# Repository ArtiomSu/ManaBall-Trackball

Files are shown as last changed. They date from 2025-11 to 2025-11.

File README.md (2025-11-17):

# Mana Ball Track Ball




A fully modular, open-source, 3D-printable trackball with customizable RGB lighting and swappable button modules. The Mana Ball features a translucent 50mm ball illuminated by 6 RGB LEDs, creating a glowing multicolor orb effect reminiscent of mana orbs in video games.

<p align="center">
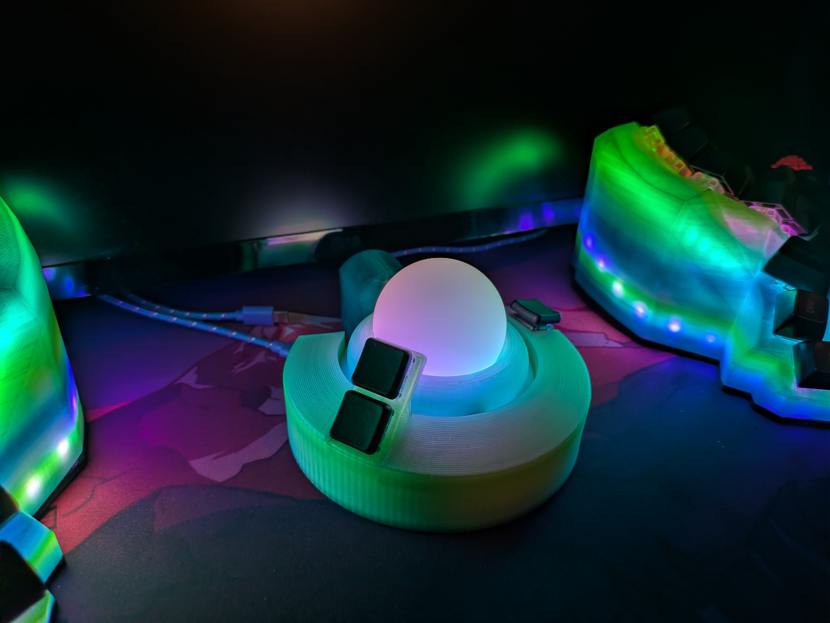
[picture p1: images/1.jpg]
Mana Ball Track Ball with button module
  
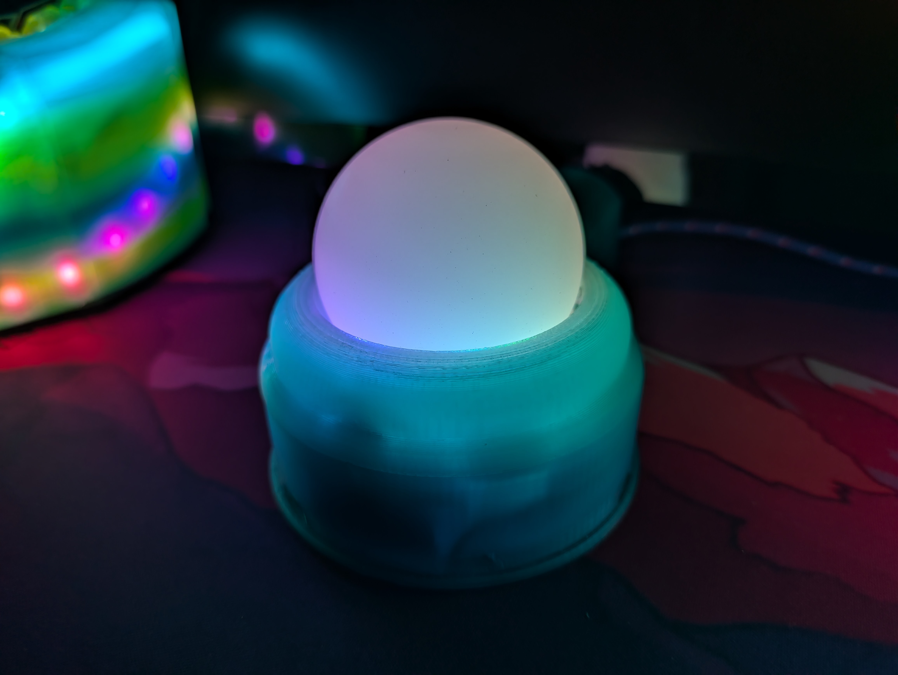
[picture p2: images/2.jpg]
Mana Ball Track Ball
  
</p>

See more photos in the [gallery](gallery.md).

Click the images below to watch introduction videos

| Mana Ball Trailer | Mana Ball Overview and Features |
|---|---|
| Mana Ball Trailer (https://www.youtube.com/watch?v=vn09xzBtV5k) | Mana Ball Overview and Features (https://www.youtube.com/watch?v=WPnU__LLYNc) |

## Table of Contents

- [Features](#features)
- [Why Mana Ball?](#why-mana-ball)
- [Getting Started](#getting-started)
  - [Materials and Tools](#materials-and-tools)
  - [3D Printing Files](#3d-printing-files)
- [Build Guide](#build-guide)
  - [Common Parts](#common-parts)
  - [Body Options](#body-options)
  - [Button Modules](#button-modules)
  - [Wrist Rests](#wrist-rests)
  - [Recommended Setup](#recommended-setup)
- [Assembly](#assembly)
  - [Wiring Diagrams](#wiring-diagrams)
  - [Assembly Videos](#assembly-videos)
- [Firmware](#firmware)
- [Configuration](#configuration)
- [Troubleshooting](#troubleshooting)
- [Contributing](#contributing)
- [License](#license)

## Features

- **Modular Design**: Hot-swappable button modules and body configurations
- **High Precision**: PMW3360 optical sensor for accurate tracking
- **Smooth Movement**: Rexroth Ball Transfer Units (BTUs) for premium feel
- **Customizable RGB**: 6 RGB LEDs with configurable lighting effects
- **Low Profile**: Ergonomic design with low-profile keyboard switches
- **Drag Scrolling**: Configurable scroll feature
- **Universal Compatibility**: Works with all operating systems via USB-C
- **Open Source**: Fully 3D printable with no custom PCBs required
- **QMK Powered**: RP2040 microcontroller running QMK firmware
- **Adjustable Settings**: Pointer speed, scroll speed, scroll direction and LED effects
- **Standard Components**: Uses any 50mm ball

## Why Mana Ball?

After years of testing various trackballs (documented in my [trackball comparison repository](https://github.com/ArtiomSu/artiomsu-trackball-comparisons-and-mods)), I found that none perfectly suited my needs. While the Ploopy Adept came close after modifications, its button layout still wasn't ideal. The Mana Ball is my solution—a trackball designed specifically for my workflow, with modularity built in so others can adapt it to theirs.

**Best used with**: A QMK-enabled keyboard or macro pad configured with [QMK RAW HID Router Software](https://github.com/ArtiomSu/QMK-Raw-HID-Router) for full customization capabilities. While the trackball can operate standalone with button modules, the HID Router unlocks features like real-time configuration.

## Getting Started

### Materials and Tools

See [materials.md](materials.md) for the complete parts list and required tools.

**What you'll need depends on your build**:
- Skip LEDs if you don't want lighting effects
- Skip hot-melt inserts if not using the optional sensor holder
- Skip keycaps/switches if building a button-less version

**Cost considerations**: The most expensive components are the Rexroth BTUs, which provide the smoothest tracking experience but are surprisingly expensive. All other parts are reasonably priced.

### 3D Printing Files

All STL files are in the [`finished stl/`](<finished stl/>) folder.

**Bambu Studio users**: A pre-configured `.3mf` project file is included with optimized print settings and bed arrangement.

This is also uploaded to [Makers World](https://makerworld.com/en/models/2009889-mana-ball-track-ball) so you can download it directly to your Bambu Lab printer if you have one.

## Build Guide

### Common Parts

These parts are required for all builds:

| Part | File | Notes |
| ---- | ---- | ----- |
| **Head** | [head.stl](<finished stl/head.stl>) | Main component holding the ball and sensor |
| **Shim** | [shim.stl](<finished stl/shim.stl>) | Secures the microcontroller inside the body |
| **Head Sensor Holder** | [head_sensor_holder.stl](<finished stl/head_sensor_holder.stl>) | Optional: Provides extra sensor security (requires hot-melt inserts in head) |

### Body Options

#### Button-Less Bodies

For use with an external keyboard for clicking:

| Part | File | Description |
| ---- | ---- | --- |
| **Body Medium** | [body_medium.stl](<finished stl/body_medium.stl>) | One-piece design with integrated controller placement. Clean aesthetics but taller profile |
| **Body Small** | [body_small.stl](<finished stl/body_small.stl>) | Compact design requiring [body_small_cap.stl](<finished stl/body_small_cap.stl>) |
| **Body Small Cap** | [body_small_cap.stl](<finished stl/body_small_cap.stl>) | Cap for small body, conceals wiring |
| **Body Small External** | [body_small_external.stl](<finished stl/body_small_external.stl>) | Compact with exposed controller. Lower profile but visible wires (test design) |

#### Bodies with Button Support

| Part | File | Description |
| ---- | ---- | --- |
| **Body Small for Buttons** | [body_small_for_buttons.stl](<finished stl/body_small_for_buttons.stl>) | Standard button-compatible body. Uses [body_small_cap.stl](<finished stl/body_small_cap.stl>) |
| **Body Small for Buttons (Wire Friendly)** | [body_small_for_buttons_bigger_more_wire_cutouts.stl](<finished stl/body_small_for_buttons_bigger_more_wire_cutouts.stl>) | Enhanced wire routing with larger cutouts. Uses [body_small_cap.stl](<finished stl/body_small_cap.stl>) |

### Button Modules

Located in [`finished stl/buttons/`](<finished stl/buttons/>).

**Note**: Button modules are functional but still WIP. Current designs provide working button positions but aesthetics are being refined.

**Compatibility**: Any button-compatible body works with any button module.

Some button modules use a cover that is secured with magnets. For example the [triple button v3.1](<finished stl/buttons/triple button v3.1.stl>) would go together with [triple button v3.1 cover](<finished stl/buttons/triple button v3.1 cover.stl>).

### Wrist rests

Located in [`finished stl/wrist rest/`](<finished stl/wrist rest/>).

**Note**: This is recommended as the ball is quite high.

**Printing tip**: Print with TPU with 1 wall for top/bottom and sides. Use 5% infill for maximum comfort. This way it keeps its shape but is just a little bit soft.

### Recommended Setup

**My current configuration**:
- Body: [body_small_for_buttons_bigger_more_wire_cutouts.stl](<finished stl/body_small_for_buttons_bigger_more_wire_cutouts.stl>)
- Buttons: [triple button v3.1](<finished stl/buttons/triple button v3.1.stl>) with [triple button v3.1 cover](<finished stl/buttons/triple button v3.1 cover.stl>).
- Wrist Rest: [wrist rest.stl](<finished stl/wrist rest/wrist rest.stl>)
- Layout: Left click, right click, and drag scroll—perfect for my workflow

## Assembly

### Wiring Diagrams

#### Without Switches

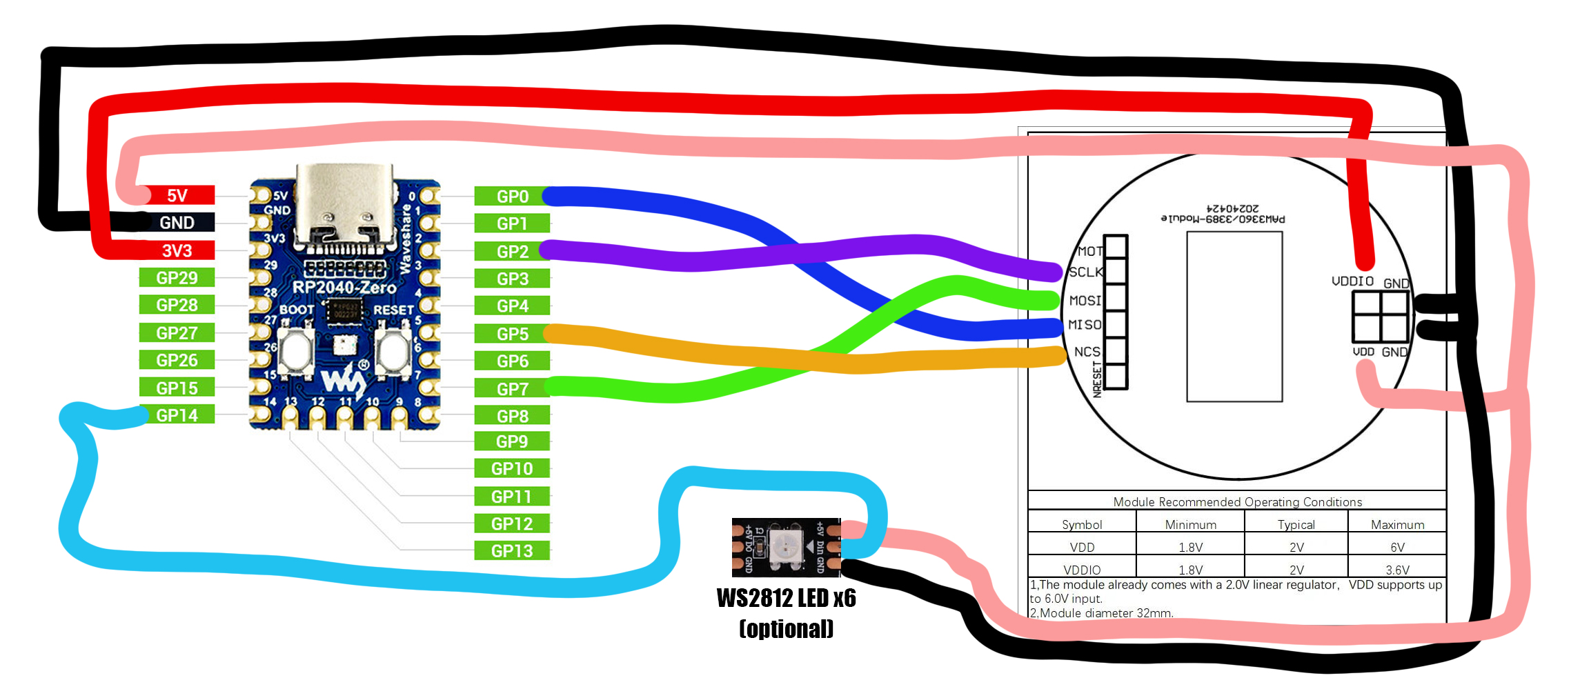
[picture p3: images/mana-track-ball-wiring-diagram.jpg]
Wiring Diagram without Switches


#### With Switches

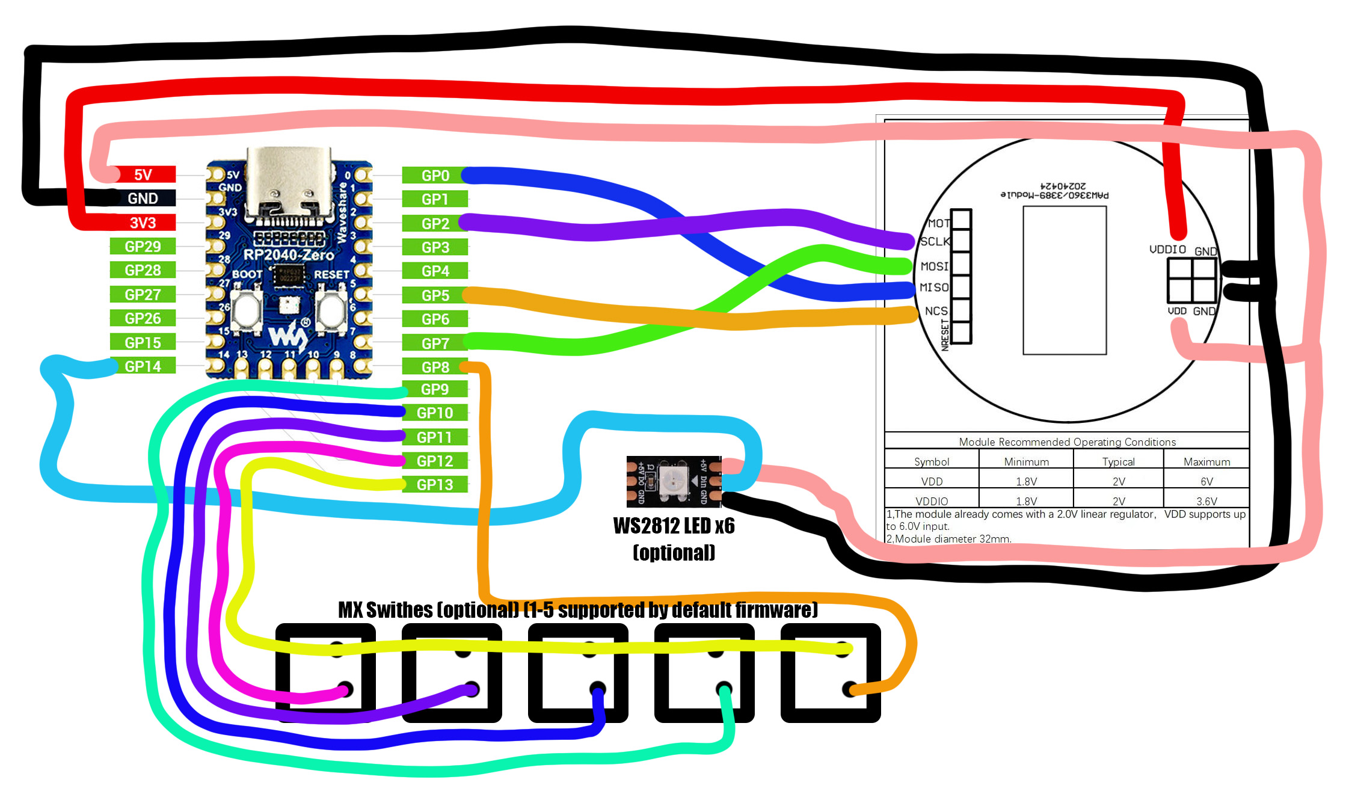
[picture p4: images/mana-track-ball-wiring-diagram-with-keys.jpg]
Wiring Diagram with Switches


**Important notes**:
- **No diodes required**: Single-row, five-column matrix supports n-key rollover without diodes
- **Expandable**: 9 additional free GPIO pins available for up to 14 total switches (requires quick firmware modification)
- **Flexible switch count**: Using fewer than 5 switches? Just populate the pins you need (starting with GP12). Unpopulated switches are simply ignored by firmware

### Assembly Videos

Follow these step-by-step video guides:

1. **[Head Assembly](https://youtu.be/o33xUQOpQcM)** - Start here, as this is the most complex and universal component
2. **[Body Assembly](https://youtu.be/YjRsaHhR8Q8)** - Attach your chosen body
3. **[Better Button Module Assembly](https://www.youtube.com/watch?v=52Slw13G3vc)** - Add buttons (if applicable)

## Firmware

### Flashing QMK Firmware

**Prerequisite**: Set up QMK on your system following the [official QMK setup guide](https://docs.qmk.fm/#/newbs_getting_started).

```bash
# Clone the firmware repository
git clone https://github.com/ArtiomSu/qmk_firmware.git
cd qmk_firmware

# Switch to the Mana Ball branch
git checkout artiomsu_manaball

# Initialize submodules
qmk git-submodule

# Clean and flash
make clean
qmk flash -kb artiomsu_manaball -km default
```

**Tip**: Flash firmware before wiring to verify the microcontroller works correctly.

If you don't want to customise the firmware, you can download pre-compiled `.uf2` files from the [Releases](https://github.com/ArtiomSu/ManaBall-Trackball/releases).

Drag and drop the `.uf2` file onto the RP2040 mounted as a USB drive. To mount the RP2040 as a USB drive, hold the BOOTSEL button while plugging it into your computer.

## Configuration

### Customizing Settings

Adjust pointer speed, scroll behavior, LED effects, and more using the [QMK RAW HID Router Software](https://github.com/ArtiomSu/QMK-Raw-HID-Router).

**Platform support**: Windows, Linux, and macOS

**Setup process**:
1. The Mana Ball is pre-configured for the HID Router
2. Configure your QMK keyboard/macro pad following the [video tutorial](https://github.com/ArtiomSu/QMK-Raw-HID-Router) at the bottom of the README
3. Control trackball settings via keyboard shortcuts

**Reference implementation**: See my [keyboard firmware](https://github.com/ArtiomSu/qmk_firmware/tree/artiom_dactyl/keyboards/artiomsu_dactyl/keymaps/linux_and_mac) for integration examples.

**Future plans**: Standalone configuration app (desktop or web-based) may be developed, but keyboard integration offers superior workflow integration with layers, macros, and synchronized settings.

## Troubleshooting

**Common Issues**:

- **Ball doesn't track smoothly**: Check BTU alignment and cleanliness
- **LEDs not lighting**: Verify LED wiring polarity and connections
- **Sensor not working**: Ensure sensor is properly seated and lens is clean
- **Buttons not responding**: Check switch wiring and verify GPIO pin connections
- **Firmware won't flash**: Ensure RP2040 is in bootloader mode (hold BOOTSEL while connecting)

**Need help?** Open an issue on GitHub with:
- Photos of your build
- Description of the problem
- What you've already tried

## Contributing

Contributions are welcome! Whether you've designed a new button module, improved a body design, or found a bug:

1. Fork the repository
2. Create a feature branch
3. Submit a pull request with clear descriptions

**Share your builds**: I'd love to see your custom modules and modifications!

## License

This project is licensed under the Creative Commons Attribution-NonCommercial-ShareAlike 4.0 International License (CC BY-NC-SA 4.0).

**This means**:
- ✅ You can use, modify, and share this design
- ✅ You must share any modifications under the same license
- ✅ You must give appropriate credit
- ❌ You cannot use this commercially without permission

See [LICENSE](LICENSE) for the full license text.

---

**Questions?** Open an issue on GitHub or check the [QMK RAW HID Router](https://github.com/ArtiomSu/QMK-Raw-HID-Router) documentation for configuration help.

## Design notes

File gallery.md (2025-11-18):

# Mana Ball Track Ball Gallery

A visual showcase of the Mana Ball's design.

## Gallery

<table>
  <tr>
    <td width="50%">
      Mana Ball - View 1
    </td>
    <td width="50%">
      Mana Ball - View 2
    </td>
  </tr>
  <tr>
    <td width="50%">
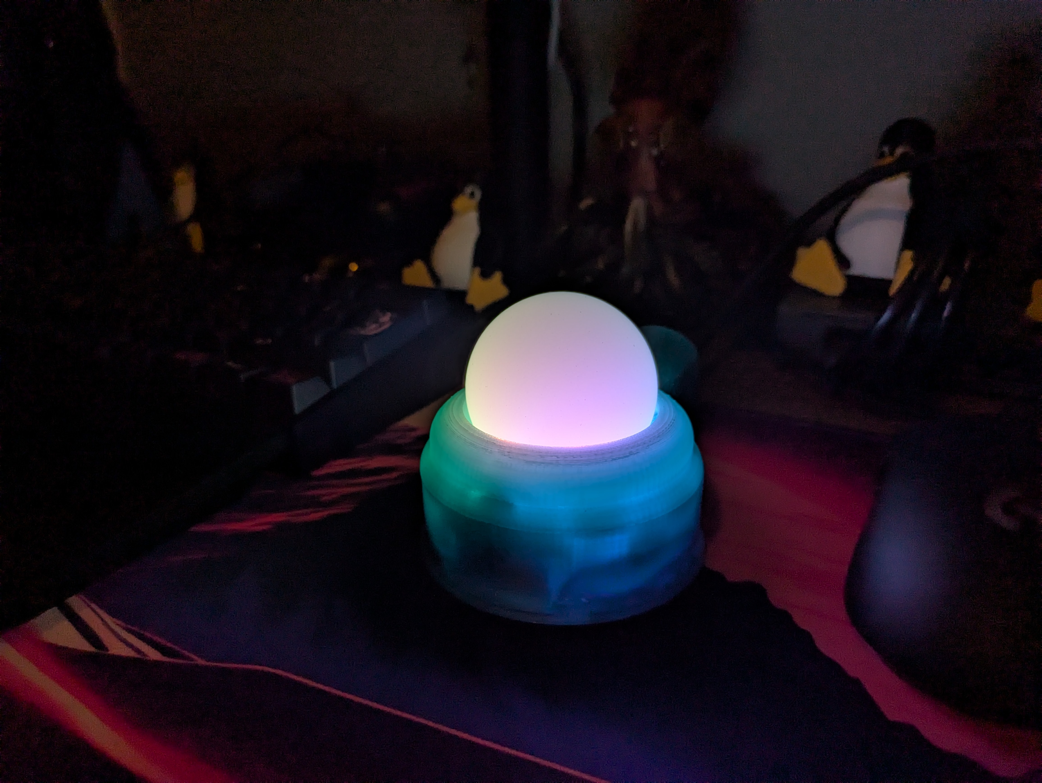
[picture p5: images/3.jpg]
Mana Ball - View 3
      
    </td>
    <td width="50%">
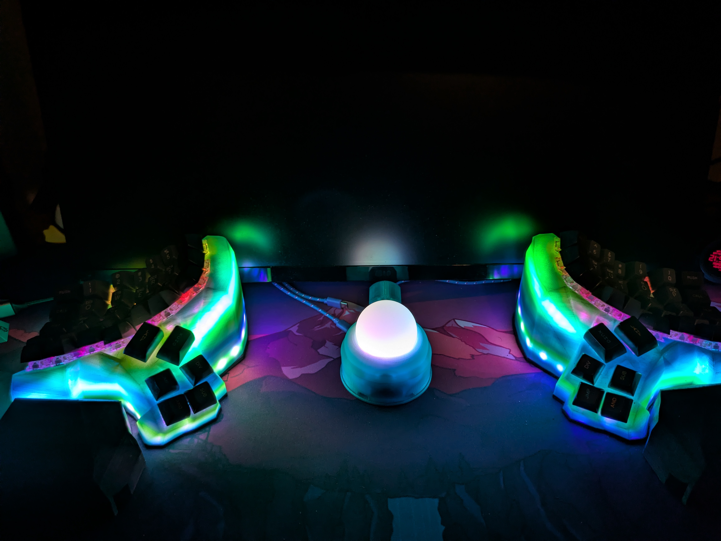
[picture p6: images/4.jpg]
Mana Ball - View 4
      
    </td>
  </tr>
  <tr>
    <td width="50%">
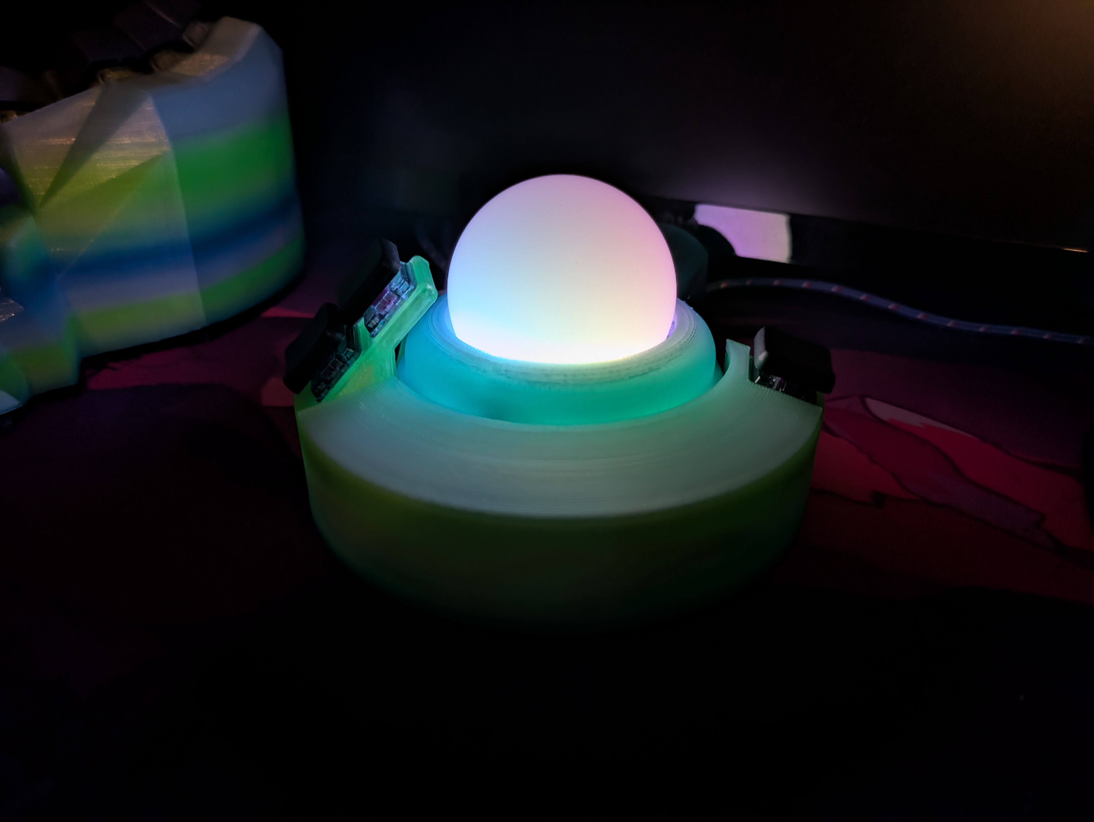
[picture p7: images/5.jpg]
Mana Ball - View 5
      
    </td>
    <td width="50%">
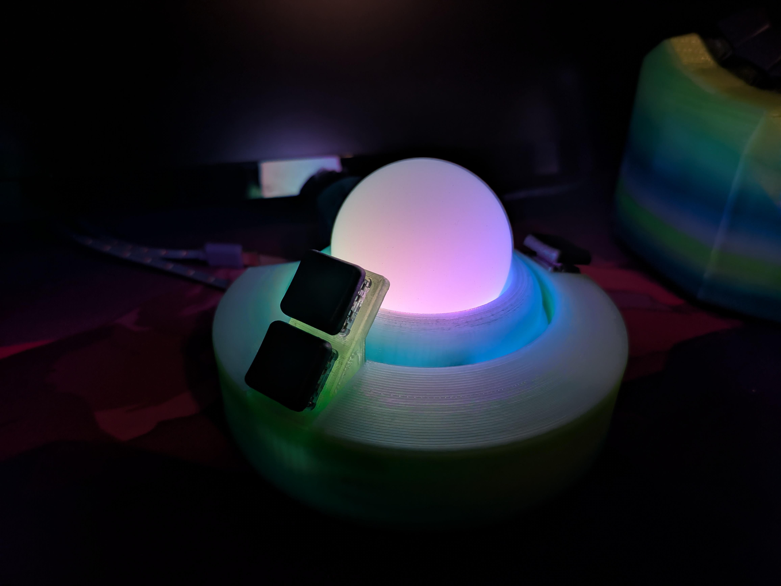
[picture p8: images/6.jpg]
Mana Ball - View 6
      
    </td>
  </tr>
  <tr>
    <td width="50%">
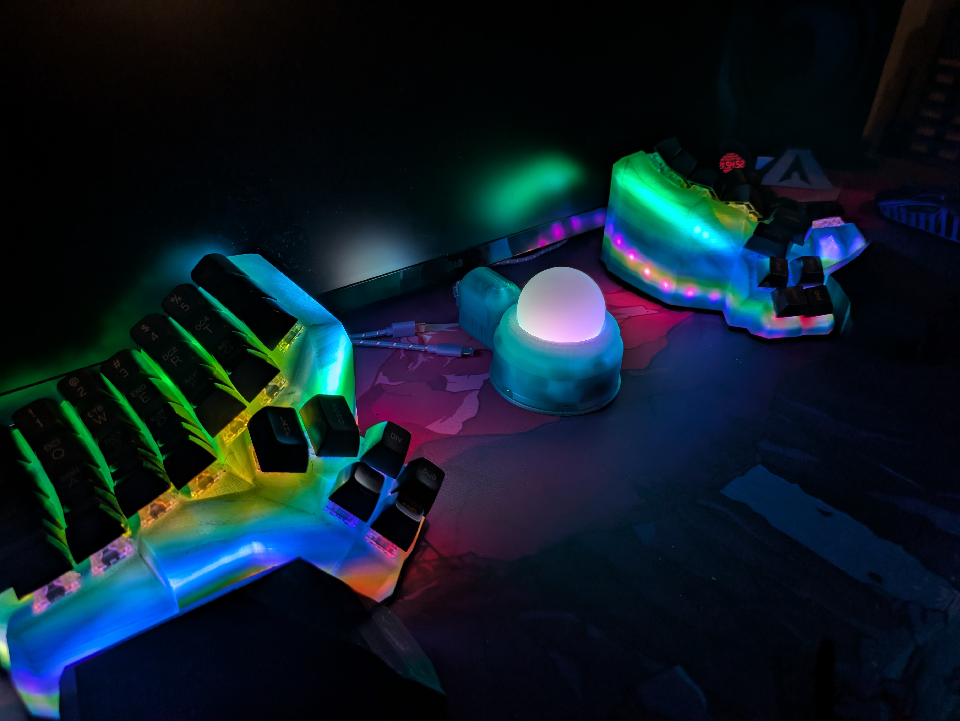
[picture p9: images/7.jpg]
Mana Ball - View 7
      
    </td>
    <td width="50%">
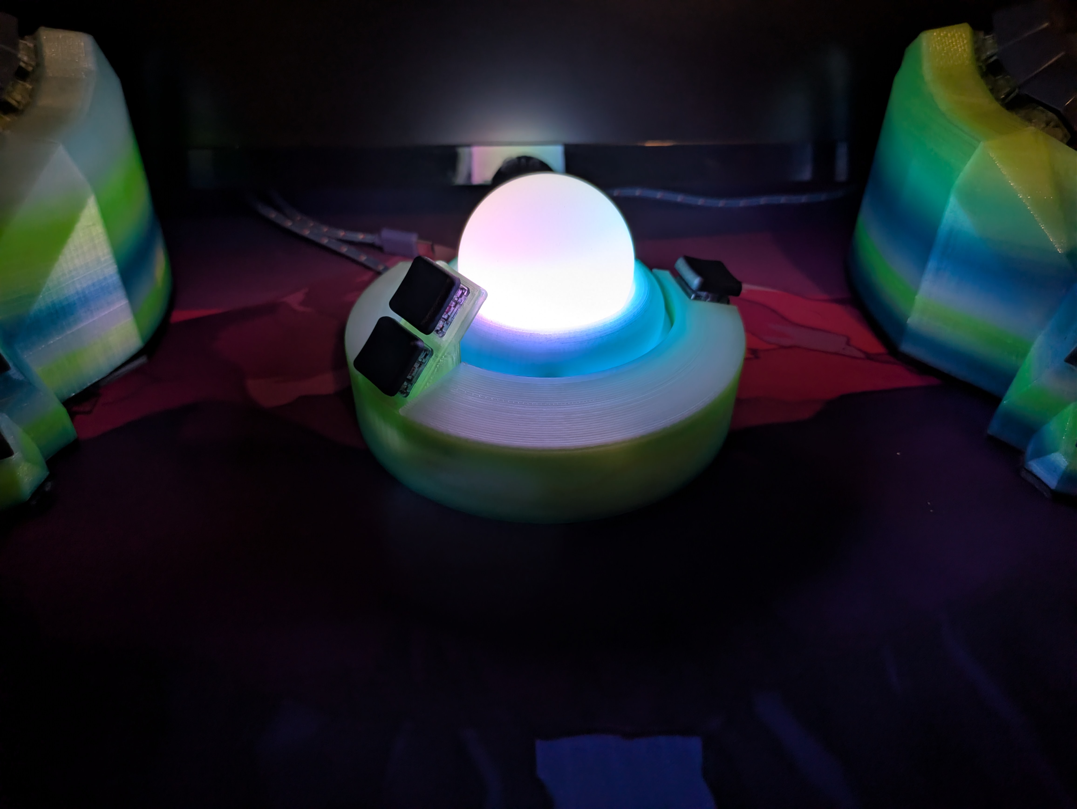
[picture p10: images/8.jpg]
Mana Ball - View 8
      
    </td>
  </tr>
  <tr>
    <td width="50%">
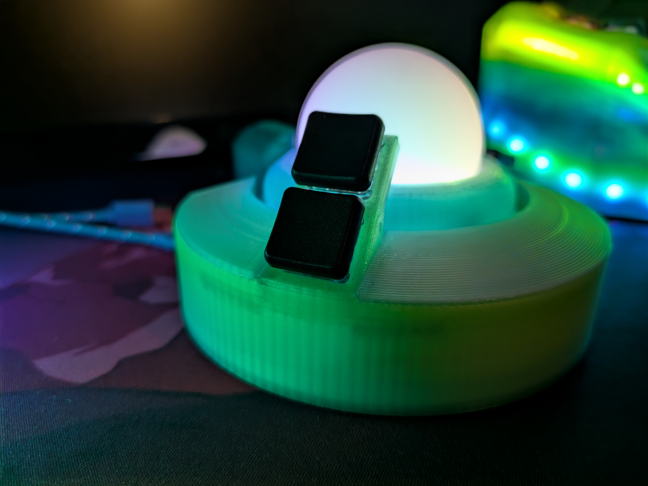
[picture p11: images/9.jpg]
Mana Ball - View 9
      
    </td>
    <td width="50%">
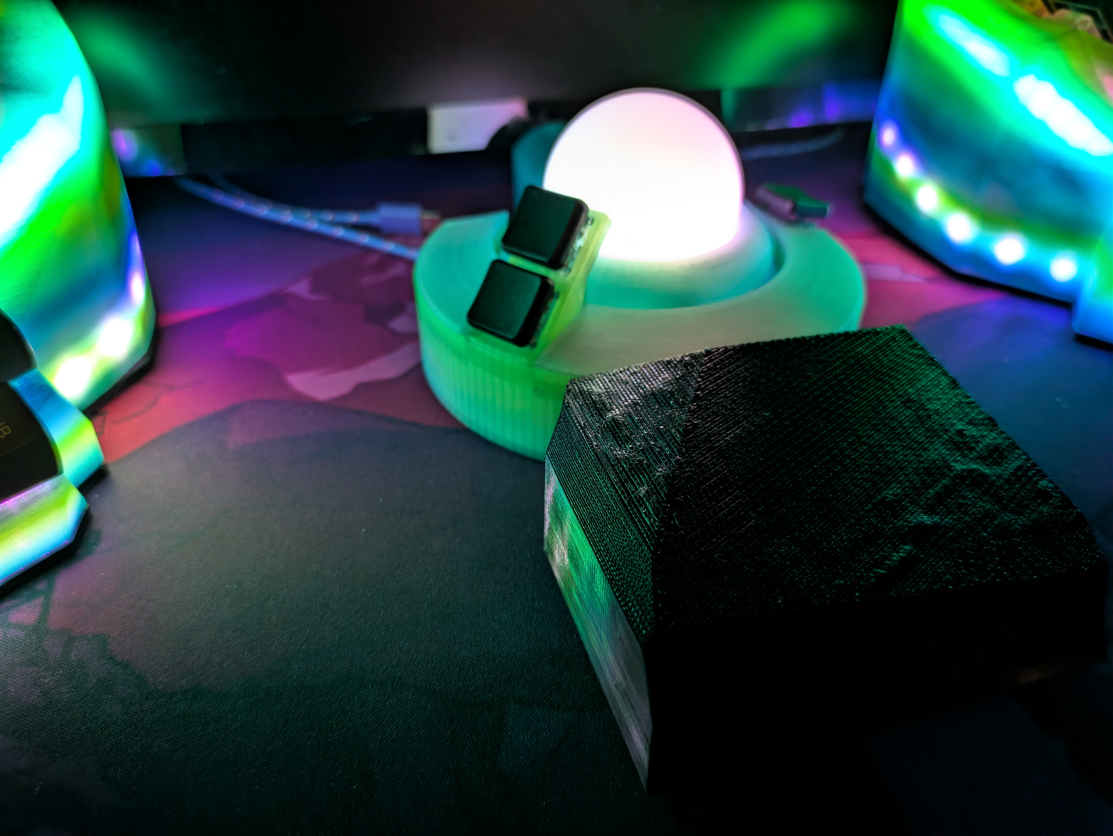
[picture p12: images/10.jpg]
Mana Ball - View 10
      
    </td>
  </tr>
  <tr>
    <td width="50%">
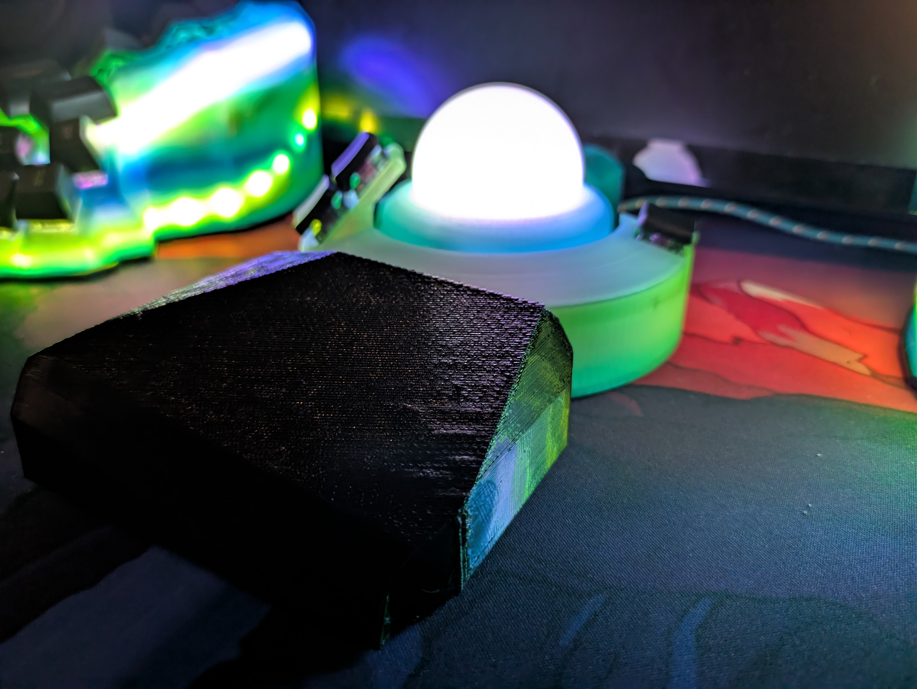
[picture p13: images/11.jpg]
Mana Ball - View 11
      
    </td>
    <td width="50%">
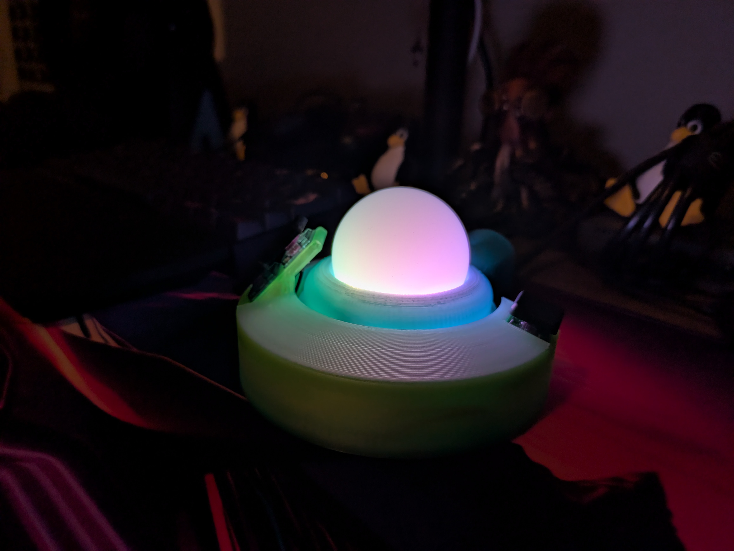
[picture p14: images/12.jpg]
Mana Ball - View 12
      
    </td>
  </tr>
  <tr>
    <td width="50%">
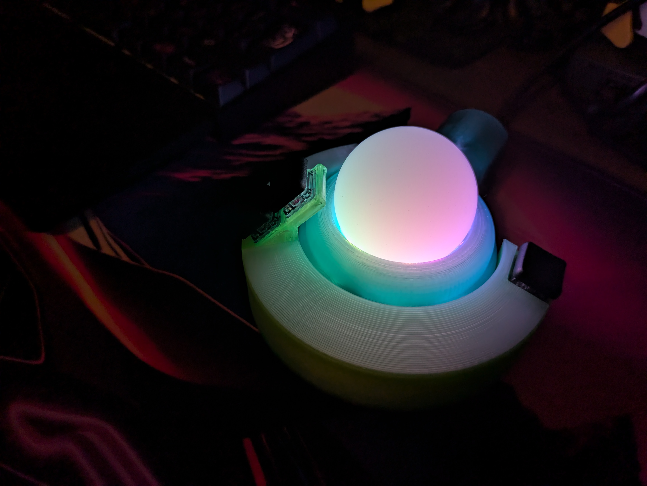
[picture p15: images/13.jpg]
Mana Ball - View 13
      
    </td>
    <td width="50%">
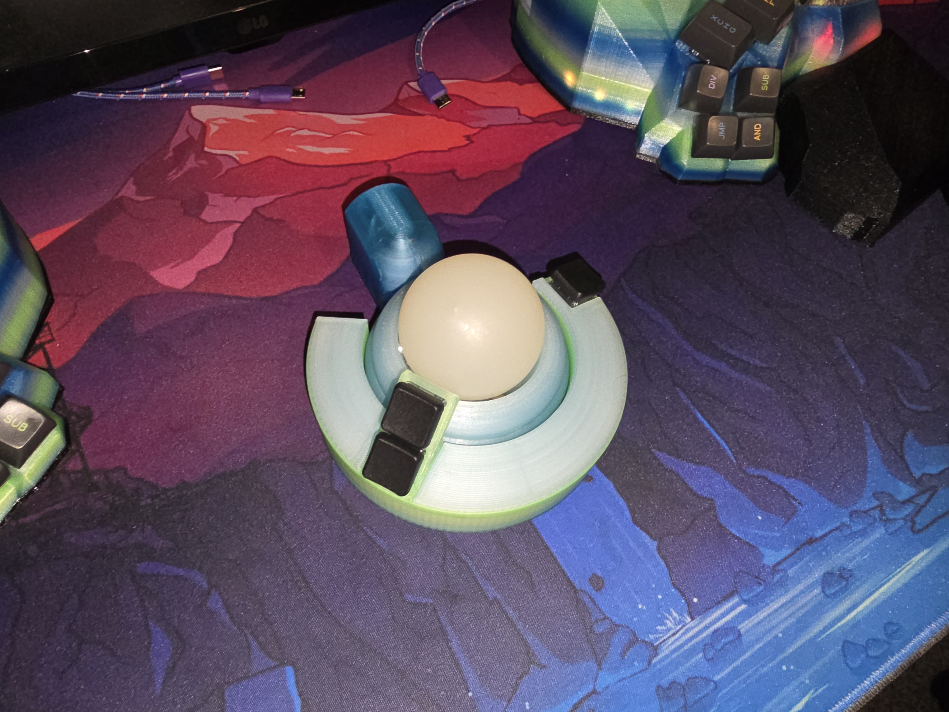
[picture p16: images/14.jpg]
Mana Ball - View 14
      
    </td>
  </tr>
  <tr>
    <td width="50%">
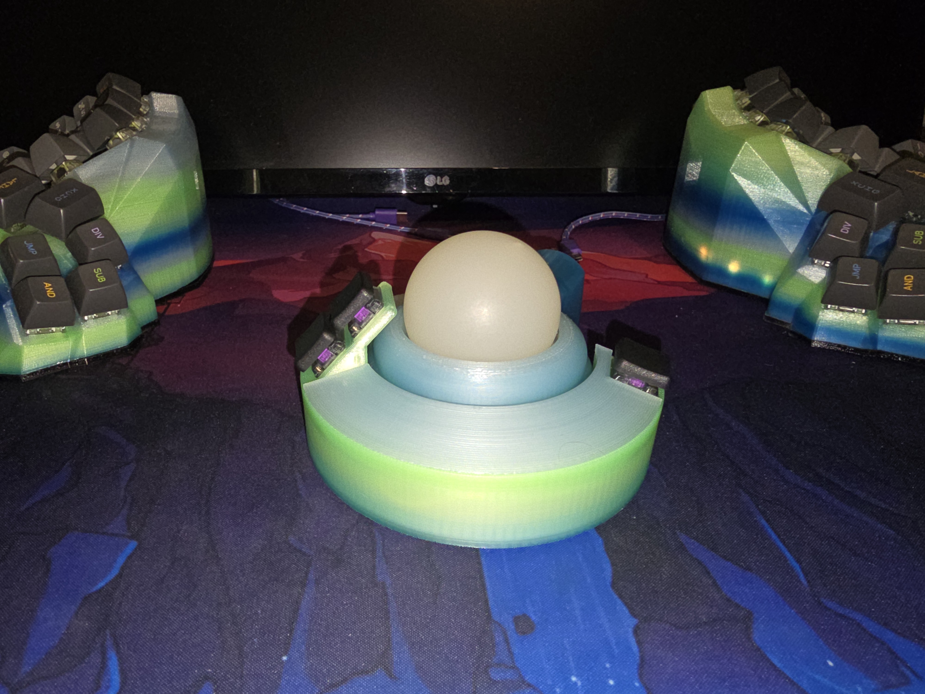
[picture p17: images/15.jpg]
Mana Ball - View 15
      
    </td>
    <td width="50%">
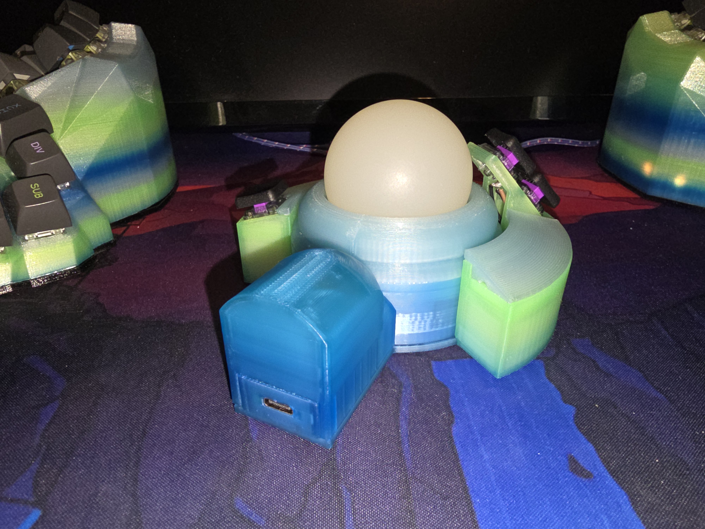
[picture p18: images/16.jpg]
Mana Ball - View 16
      
    </td>
  </tr>
  <tr>
    <td colspan="2" align="center">
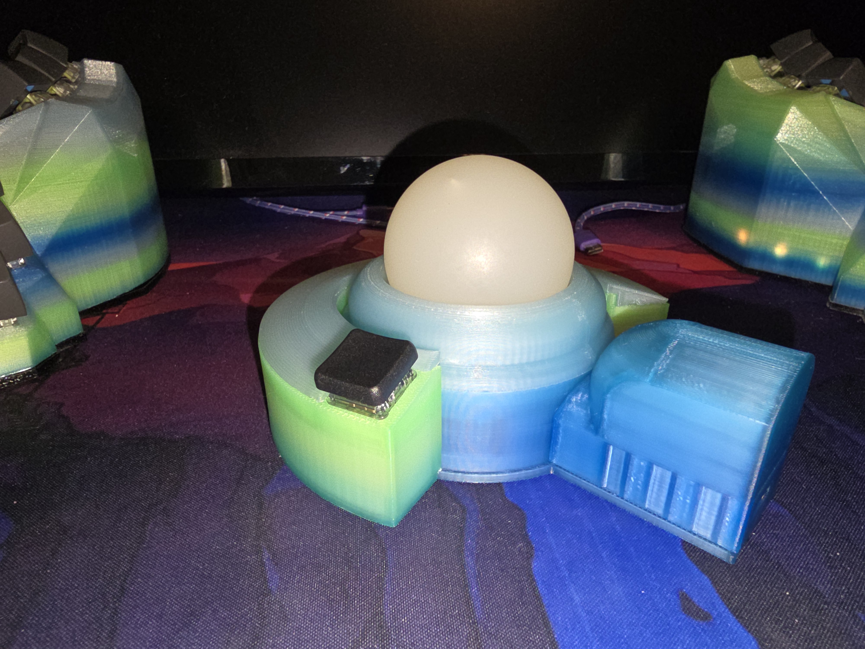
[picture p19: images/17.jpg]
Mana Ball - View 17
      
    </td>
  </tr>
</table>

---

[← Back to README](README.md)

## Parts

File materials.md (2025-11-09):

# Parts list for Mana Track Ball

| quantity | optional | part | link | price |
| --- | --- | ---- | ---- | ----- |
| 1 | No  | PMW3360 module | [aliexpress](https://www.aliexpress.com/item/1005007729769668.html) | ~€22 |
| 3 | No  | Rexroth BTU | [spareparts](https://www.sp-spareparts.com/en/p/r053010810-bosch-rexroth) | ~€50 |
| 1 | No  | rp2040 zero usb c | [aliexpress](https://www.aliexpress.com/item/1005007650325892.html) | €3 |
| 1 | No  | 50mm POM ball | [aliexpress](https://www.aliexpress.com/item/1005005059570859.html) | €7 |
| 2 | Yes | hot melt insert m2 (OD 3.2mm) 50 pack | [aliexpress](https://www.aliexpress.com/item/1005003582355741.html) | €2.50 |
| 2 | Yes | m2 10mm bolt 50 pack | [aliexpress](https://www.aliexpress.com/item/32810852732.html) | €2.00 |
| 1 | Yes | Rubber feet 6mm (pack of 50, we will only use 6) | [aliexpress](https://www.aliexpress.com/item/32963141746.html) | €3 |
| 1 | Yes | LED strip 144 leds/m (we will only use 6 leds from whole strip) | [aliexpress](https://www.aliexpress.com/item/1005007982624217.html) | €10 |
| 6 | No | 10mm x 1mm round magnets 50 pack | [aliexpress](https://www.aliexpress.com/w/wholesale-magnets-neodymium-10x1mm.html) | €2.50 |
| 1+ | Yes | Low profile keycaps (6 pack) | [aliexpress](https://www.aliexpress.com/item/1005005902080016.html) | €3.30 |
| 1+ | Yes | Low profile switch (10 pack) | [aliexpress](https://www.aliexpress.com/item/1005005066585322.html) | €8.41 |

The hot melt insert stuff above is optional because the friction fit is more than good enough for the sensor. If the sensor falls out for you, then you can secure it with the inserts and m2 screws.

The leds are also optional if you don't want the led lights for some reason, the firmware will still work without any leds attached since it doesn't really care if you have the pin connected or not, it will still send out the signal into thin air.

# Tools needed to Make it

| tool | link | price |
| ---- | ---- | ----- |
| soldering iron with adjustable temperature | got some random one on amazon | €20 |
| long nose pliers | got some random one in local shop | €3 |
| 3d printer (any will do these days. I use the Bambu labs a1)  | Bambu Labs EU | €500 |
| any filament you want (need only around 100g depending on your infill %) | amazon | €20 |
| Wire cutters (these should already be part of your 3d printer tools) | aliexpress | €3 |
| helping hands (to hold the wires while you are soldering) | local shop | €20 |
| wires for connecting everything (10 pin ribbon cable) can also use the regular arduino ones so you can easily connect and disconnect | [amazon](https://www.amazon.co.uk/dp/B09R42ZGQD) | €7 |
| hot melt insert kit | [aliexpress](https://www.aliexpress.com/item/1005006208845574.html) | €4 |

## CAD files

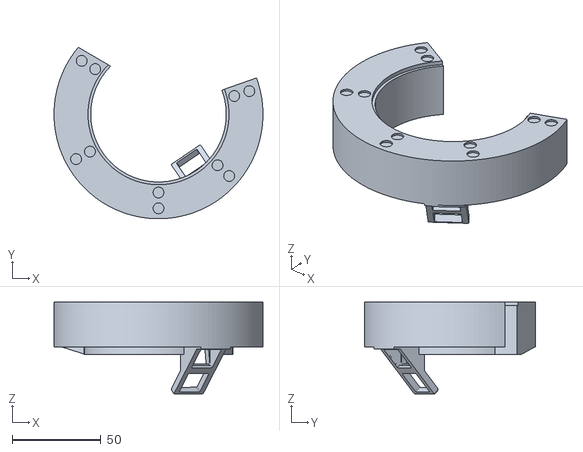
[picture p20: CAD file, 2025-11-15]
finished stl/buttons/triple button v3.1.stl
118.0 x 96.8 x 51.8

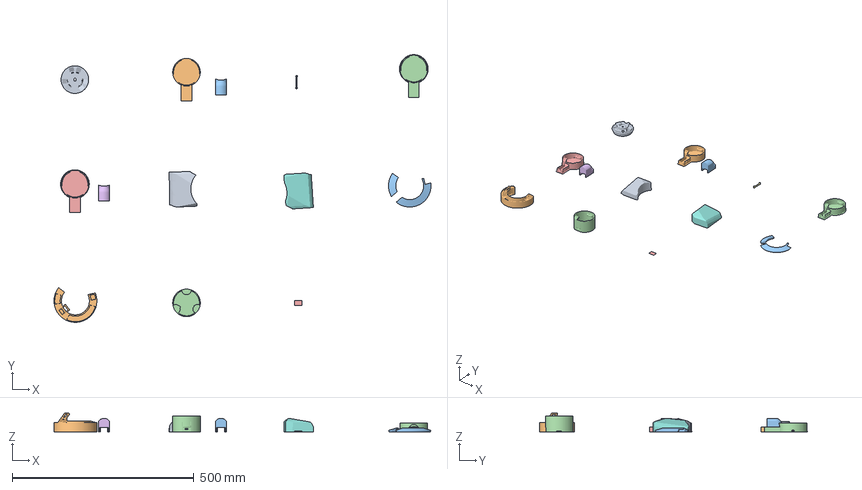
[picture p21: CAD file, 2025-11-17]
finished stl/head.3mf
1037.3 x 736.6 x 51.8 mm
head.stl
body_small.stl
body_small_cap.stl x 2
body_small_for_buttons.stl
body_small_for_buttons_bigger_more_wire_cutouts.stl
head_sensor_holder.stl
wrist rest.stl
wrist rest deeper.stl
triple button v3.1.stl
triple button v3.1 cover.stl
body_medium.stl
shim.stl

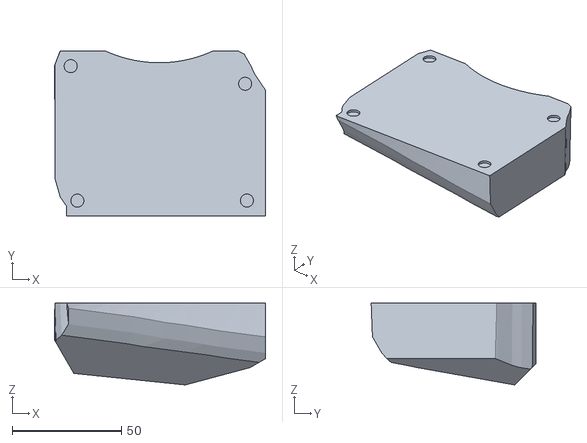
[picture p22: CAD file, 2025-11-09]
finished stl/wrist rest/wrist rest.stl
96.6 x 75.4 x 37.5

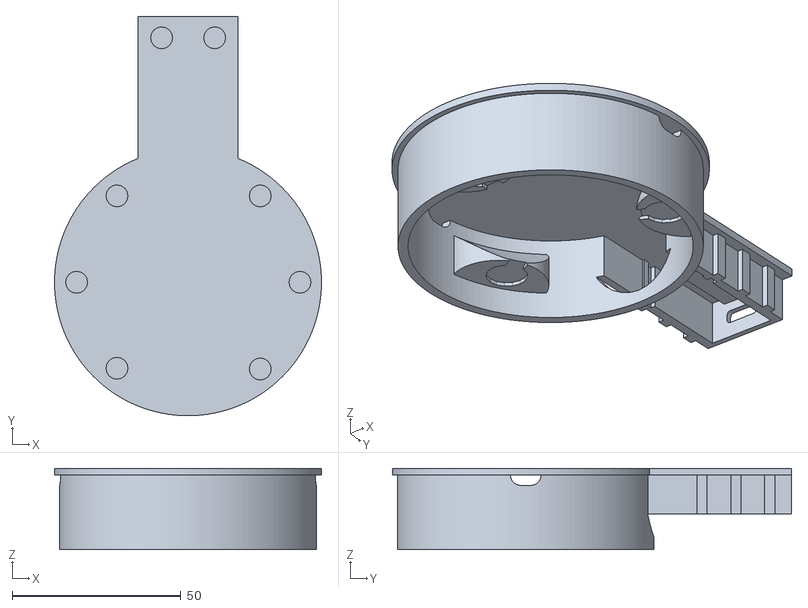
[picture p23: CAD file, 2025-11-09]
finished stl/body_small_for_buttons.stl
79.0 x 118.2 x 24.0

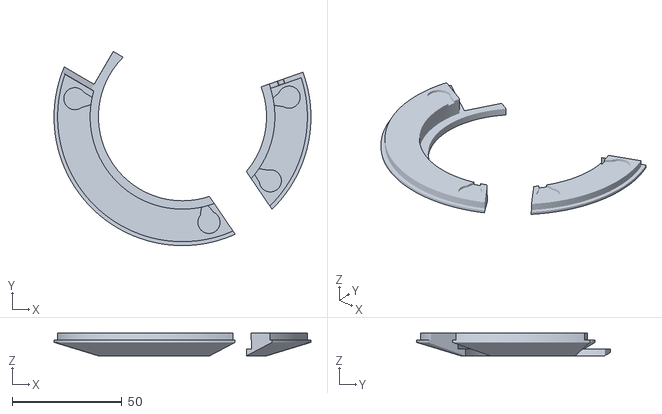
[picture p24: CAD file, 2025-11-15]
finished stl/buttons/triple button v3.1 cover.stl
117.0 x 88.4 x 10.2

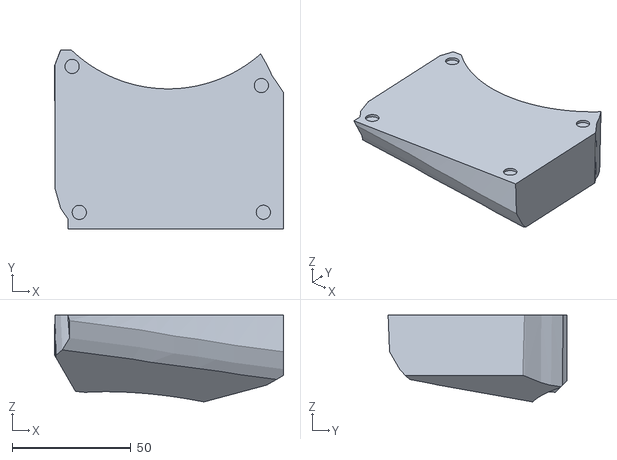
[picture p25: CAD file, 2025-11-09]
finished stl/wrist rest/wrist rest deeper.stl
96.6 x 75.4 x 36.6

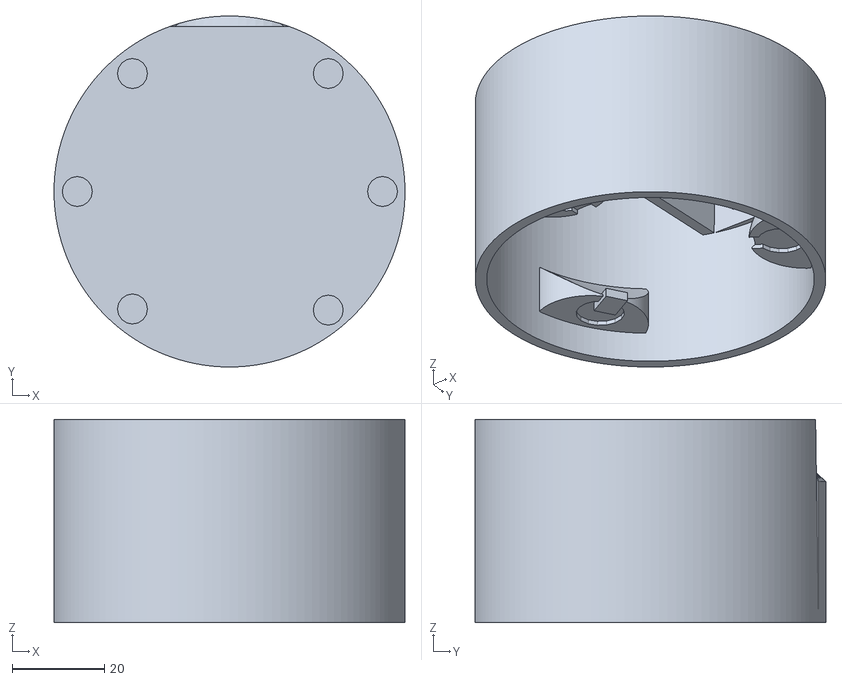
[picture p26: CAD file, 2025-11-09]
finished stl/body_medium.stl
76.0 x 76.0 x 44.0

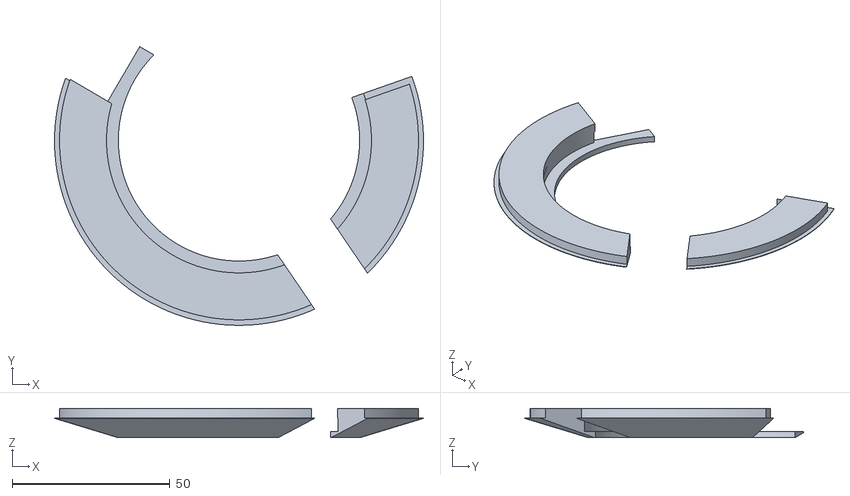
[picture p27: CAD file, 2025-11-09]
finished stl/buttons/triple button v2 cover v2.1.stl
117.0 x 88.4 x 9.24

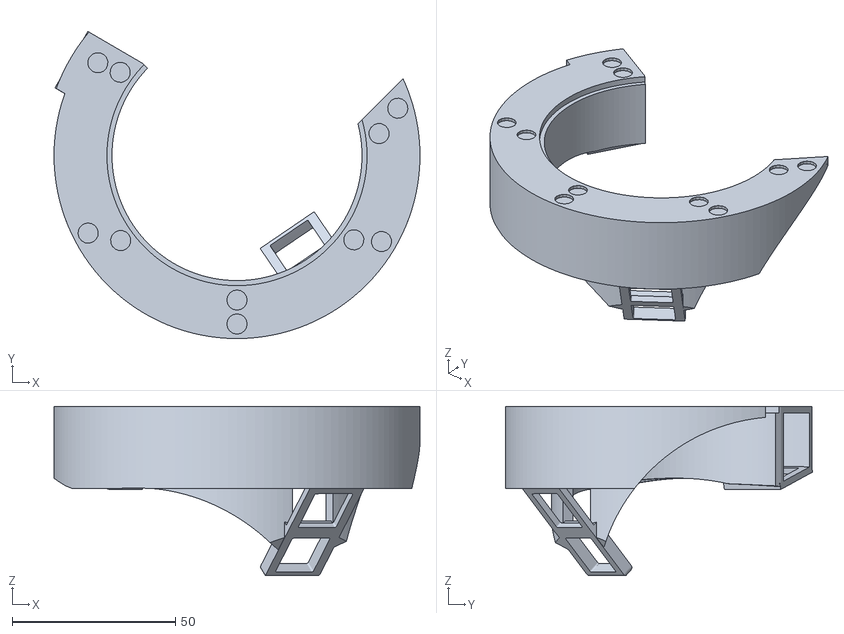
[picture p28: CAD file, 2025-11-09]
finished stl/buttons/simple triple button test v2 higher.stl
112.0 x 94.0 x 51.8

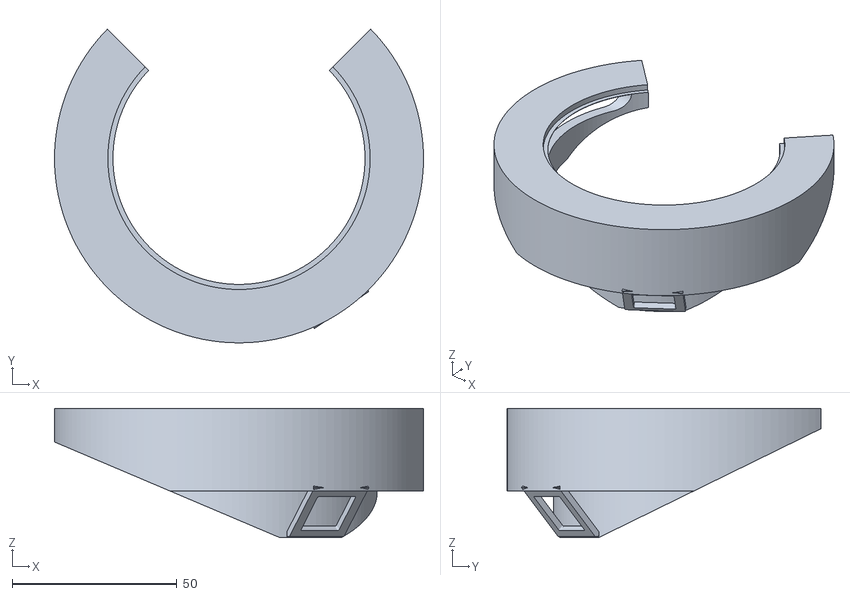
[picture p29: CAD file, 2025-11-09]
finished stl/buttons/simple single button test flipped v2.stl
112.0 x 95.2 x 39.2

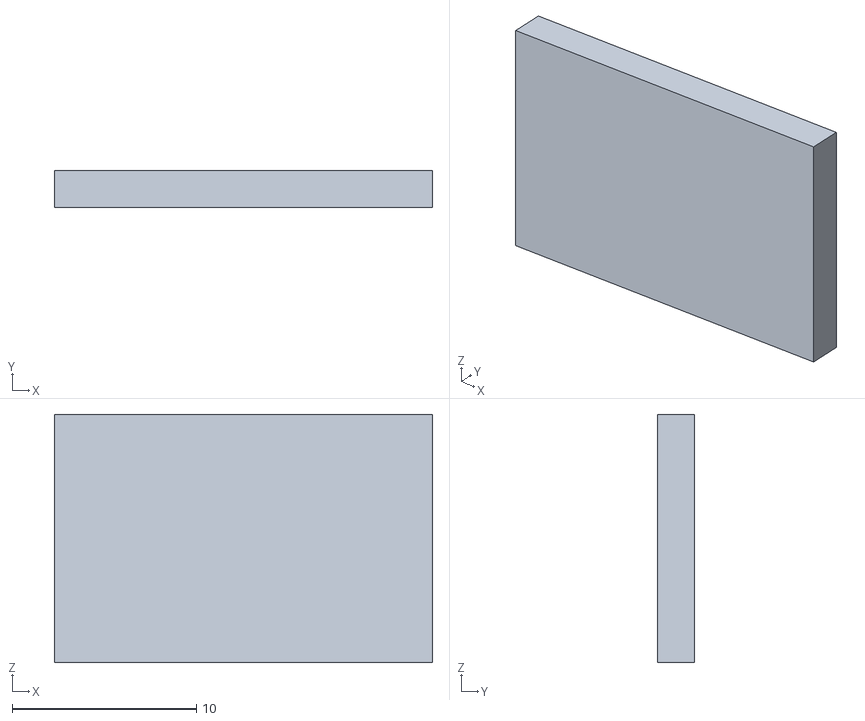
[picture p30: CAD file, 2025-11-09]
finished stl/shim.stl
20.5 x 2.00 x 13.5

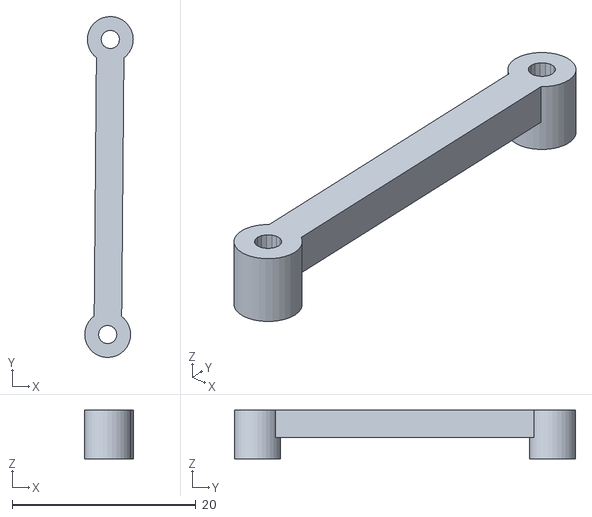
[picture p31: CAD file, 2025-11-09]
finished stl/head_sensor_holder.stl
5.29 x 37.1 x 5.30

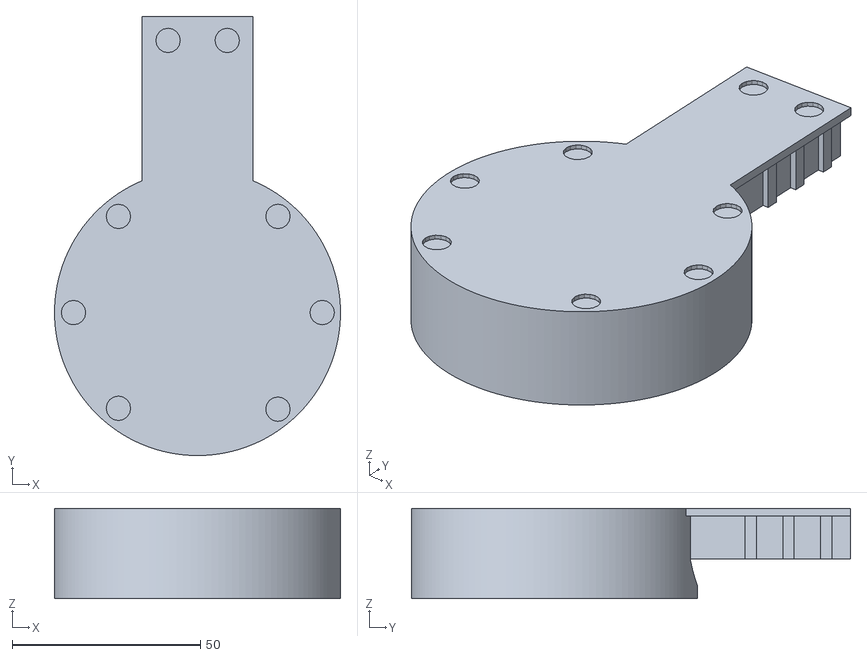
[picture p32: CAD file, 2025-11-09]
finished stl/body_small.stl
76.0 x 116.7 x 24.0

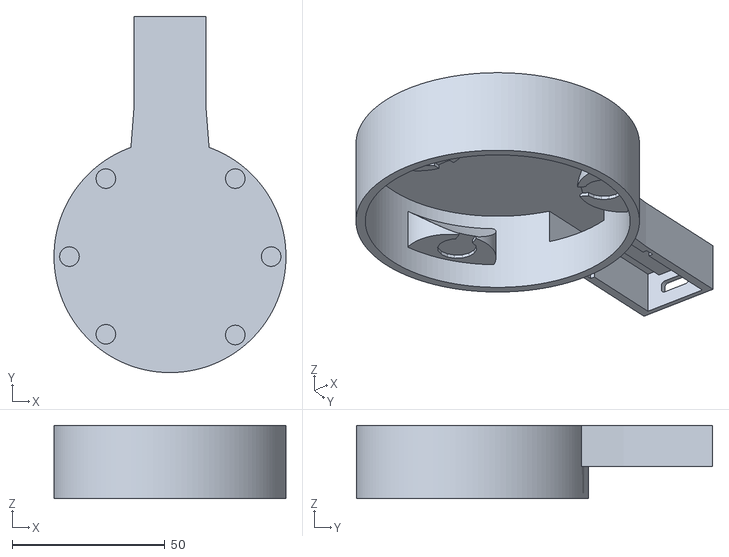
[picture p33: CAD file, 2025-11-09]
finished stl/body_small_external.stl
76.0 x 116.7 x 24.0

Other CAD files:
finished stl/body_small_for_buttons_bigger_more_wire_cutouts.stl
finished stl/buttons/simple single button test.stl
finished stl/buttons/simple single button test flipped v2 with rubber feet.stl
finished stl/buttons/triple button v2 cover v2.stl
finished stl/buttons/simple single button test flipped.stl
finished stl/buttons/simple triple button test.stl
finished stl/buttons/triple button v2 cover.stl
finished stl/buttons/triple button v2.1.stl
finished stl/buttons/triple button v2.stl
finished stl/buttons/triple button v3 cover.stl
finished stl/buttons/triple button v3.stl
finished stl/buttons/triple button.stl
finished stl/head.stl

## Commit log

2025-11-15 add images, add gallery. update readme to have new video links
    [head.3mf, triple button v3.1 cover.stl, triple button v3.1.stl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]
2025-11-17 updated model. and updated readme for release
    [head.3mf]
